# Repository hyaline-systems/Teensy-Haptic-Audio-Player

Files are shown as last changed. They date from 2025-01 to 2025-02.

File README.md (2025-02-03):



# Teensy-Haptic-Audio-Player

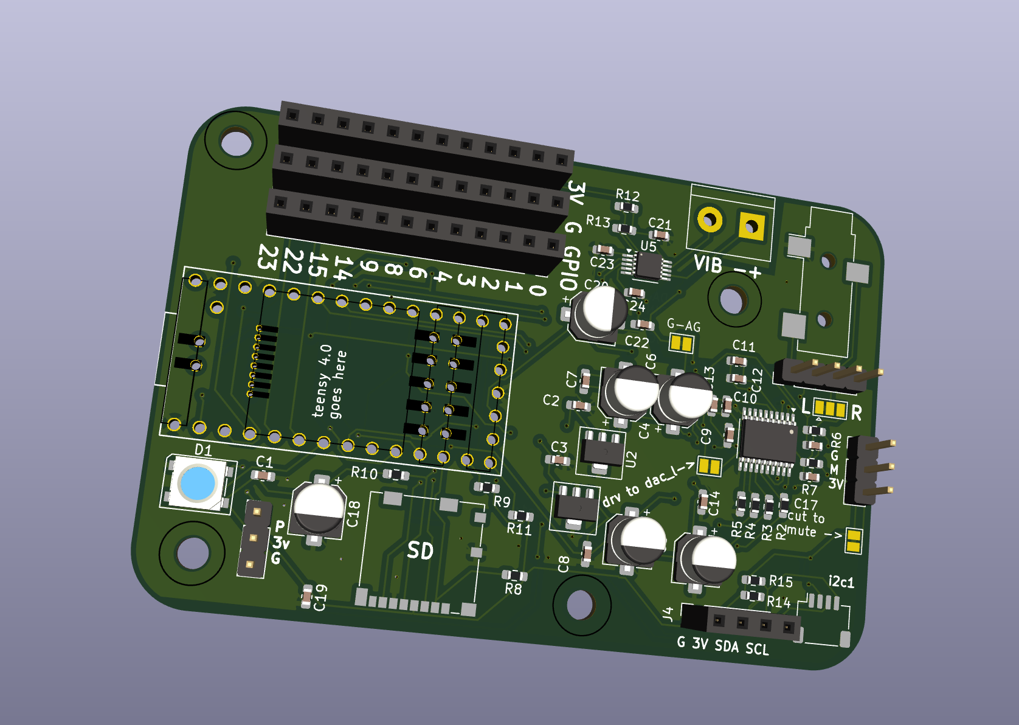
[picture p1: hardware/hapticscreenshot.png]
the PCB
 

A PCB designed for audio and haptic projects with [a Teensy 4.0](https://www.pjrc.com/store/teensy40.html). 

Among other things, it can be used to play audio from the computer as a sound card when connected via USB or from audio files via the on board SD card reader. The audio will then be output both to a 3.5mm audio jack and a haptic driver that will make a vibration motor [like this one](https://www.adafruit.com/product/1201) vibrate in sync with the audio, kinda like in a gamepad, sex toy or phone.

Another usecase is simply as a high quality audio development platform.

The whole thing is open source and hackable and is designed to be used for many different scenarios.

See [hyaline.systems](https://hyaline.systems) for more information. 

## Buying

You can buy a board, either bare (no components) or SMD-populated (no Teensy included) by sending an email to [hi@hyaline.systems](mailto:hi@hyalyne.systems).

If you just want to support the project, [consider making a donation through kofi](https://ko-fi.com/madskjeldgaard).

## Features

- Designed for the very powerful Teensy 4.0 board.
- High quality i2s stereo output DAC with 3.5mm line out jack: [PCM5102A DAC](https://www.ti.com/product/PCM5102A) – this DAC is widely compatible with all platforms and SDK's, including Arduino and C.
- SD card reader
- NeoPixel
- StemmaQT connector for easy i2c expansion.
- Optional: Hardware mute button may be connected directly to DAC.
- All unused pins broken out with lots of ground and power pins to make external connections easy
- Self-documenting board: All pins and connections are written on the board itself.

## Software

See [software/examples](software/examples) for example code using Arduino.

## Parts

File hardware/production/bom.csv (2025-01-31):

Designator | Footprint | Quantity | Value | LCSC Part #
3vpins1, GNDpins1, extra_gpio1 | PinSocket_1x12_P2.54mm_Vertical | 3 | Conn_01x12
C1, C10, C11, C12, C13, C21, C23, C24 | 0603 | 8 | 1uf
C14, C19, C2, C22, C3, C7, C8, C9 | 0603 | 8 | 0.1uf
C15, C18, C20, C4, C5, C6 | CP_Elec_5x5.7 | 6 | 10uf
C16, C17 | 0603 | 2 | 1nf
D1 | LED_SK6812_PLCC4_5.0x5.0mm_P3.2mm | 1 | SK6812
J1 | PinHeader_1x04_P2.54mm_Vertical | 1 | Conn_01x04
J2 | Jack_3.5mm_CUI_SJ-3523-SMT_Horizontal | 1 | AudioJack3
J3 | microSD_HC_Molex_104031-0811 | 1 | Micro_SD_Card
J4 | PinSocket_1x04_P2.54mm_Vertical | 1 | Conn_01x04_Pin
MUTE1, NEOPIXEL_OUT1 | PinHeader_1x03_P2.54mm_Vertical | 2 | Conn_01x03
R10, R11, R8, R9 | 0603 | 4 | 47k
R12, R13, R14, R15 | 0603 | 4 | 10k
R2, R3, R4, R5 | 0603 | 4 | 22
R6, R7 | 0603 | 2 | 470
STEMMA_QT_I2C1 | JST_SH_SM04B-SRSS-TB_1x04-1MP_P1.00mm_Horizontal | 1 | JST_SH_SM04
U1 | Teensy40_SMT | 1 | Teensy4.0
U2, U3 | SOT-89-3 | 2 | AP7365-33YG
U4 | TSSOP-20_4.4x6.5mm_P0.65mm | 1 | PCM5102A
U5 | VSSOP-10_3x3mm_P0.5mm | 1 | DRV2605LDGS
VIBMTR1 | TerminalBlock_bornier-2_P5.08mm | 1 | VIBMTR

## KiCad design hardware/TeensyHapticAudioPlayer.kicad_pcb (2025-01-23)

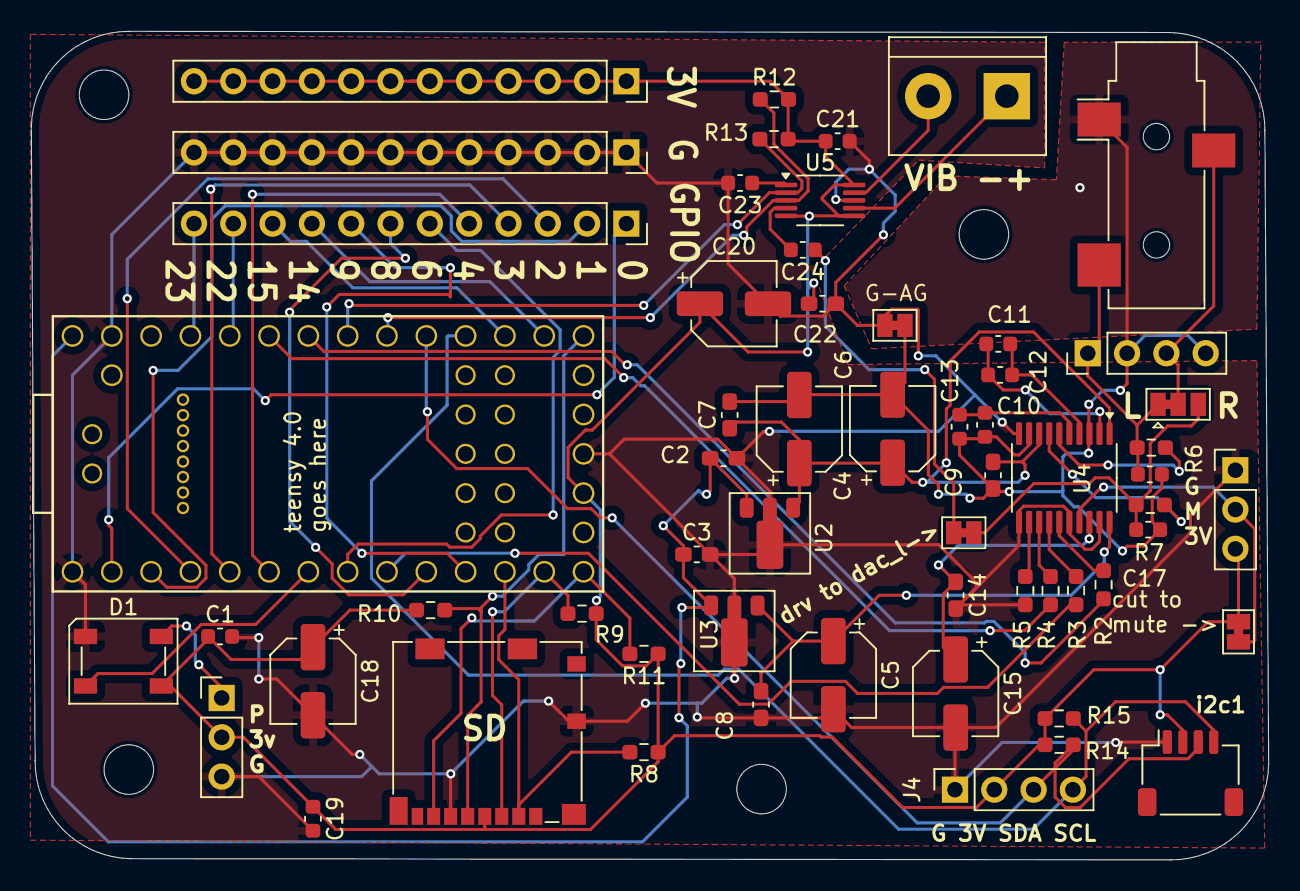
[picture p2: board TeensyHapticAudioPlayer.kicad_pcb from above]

Board: 2 copper layers, 79.9 x 53.5 mm, 63 parts (0 on the bottom side), 50 nets.

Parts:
3vpins1: Conn_01x12; PinSocket_1x12_P2.54mm_Vertical
AGND_BRIDGE1, AGND_BRIDGE2: AGND_BRIDGE; SolderJumper-2_P1.3mm_Bridged_Pad1.0x1.5mm
C1, C10, C11, C12, C13, C21, C23, C24: 1uf; C_0603_1608Metric
C2, C3, C7, C8, C9, C14, C22: 0.1uf; C_0603_1608Metric_Pad1.08x0.95mm_HandSolder
C4, C5, C6, C15, C18, C20: 10uf; CP_Elec_5x5.7
C16, C17: 1nf; C_0603_1608Metric
C19: 0.1uf; C_0603_1608Metric
D1: SK6812; LED_SK6812_PLCC4_5.0x5.0mm_P3.2mm
GNDpins1: Conn_01x12; PinSocket_1x12_P2.54mm_Vertical
H1, H2, H3, H4: MountingHole; MountingHole_3.2mm_M3
J1: Conn_01x04; PinHeader_1x04_P2.54mm_Vertical
J2: AudioJack3; Jack_3.5mm_CUI_SJ-3523-SMT_Horizontal
J3: Micro_SD_Card; microSD_HC_Molex_104031-0811
J4: Conn_01x04_Pin; PinSocket_1x04_P2.54mm_Vertical
JP1: MUTE_BRIDGE; SolderJumper-2_P1.3mm_Bridged_Pad1.0x1.5mm
JP6: SolderJumper_3_Bridged12; SolderJumper-3_P1.3mm_Bridged12_Pad1.0x1.5mm
MUTE1: Conn_01x03; PinHeader_1x03_P2.54mm_Vertical
NEOPIXEL_OUT1: Conn_01x03; PinHeader_1x03_P2.54mm_Vertical
R2, R3, R4, R5: 22; R_0603_1608Metric_Pad0.98x0.95mm_HandSolder
R6, R7: 470; R_0603_1608Metric_Pad0.98x0.95mm_HandSolder
R8, R9, R10, R11: 47k; R_0603_1608Metric_Pad0.98x0.95mm_HandSolder
R12, R13, R14, R15: 10k; R_0603_1608Metric_Pad0.98x0.95mm_HandSolder
STEMMA_QT_I2C1: JST_SH_SM04; JST_SH_SM04B-SRSS-TB_1x04-1MP_P1.00mm_Horizontal
U1: Teensy4.0; Teensy40_SMT
U2, U3: AP7365-33YG; SOT-89-3
U4: PCM5102A; TSSOP-20_4.4x6.5mm_P0.65mm
U5: DRV2605LDGS; VSSOP-10_3x3mm_P0.5mm
VIBMTR1: VIBMTR; TerminalBlock_bornier-2_P5.08mm
extra_gpio1: Conn_01x12; PinSocket_1x12_P2.54mm_Vertical

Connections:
+3.3V: 3vpins1.1, 3vpins1.2, 3vpins1.3, 3vpins1.4, 3vpins1.5, 3vpins1.6, 3vpins1.7, 3vpins1.8, 3vpins1.9, 3vpins1.10, 3vpins1.11, 3vpins1.12, C1.1, C18.1, C19.1, C20.1, C21.1, C22.1, D1.3 (VDD), J3.4 (VDD), J4.2, JP1.2 (B), MUTE1.3, NEOPIXEL_OUT1.2, R8.1, R9.1, R10.1, R11.1, R12.2, R13.2, R14.1, R15.2, STEMMA_QT_I2C1.2, U1.16 (3V3), U5.5 (EN), U5.6 (VDD/NC), U5.10 (VDD)
+5V: C2.1, C3.1, U1.33 (VIN), U2.3 (IN), U3.3 (IN)
/AGND: AGND_BRIDGE1.1 (A), C4.2, C6.2, C7.2, C9.2, C10.2, C13.2, C16.2, C17.2, J1.2, J1.4, J2.S, U4.3 (CPGND), U4.9 (AGND)
/DAC_BCK: R4.1, U1.28 (21_A7_RX5_BCLK1)
/DAC_DIN: R3.1, U1.9 (7_RX2_OUT1A)
/DAC_LRCK: R2.1, U1.27 (20_A6_TX5_LRCLK1)
/DAC_MUTE: JP1.1 (A), MUTE1.2, U4.17 (XSMT)
/DAC_OUT_L: C16.1, J1.1, J2.T, JP6.1 (A), R6.1
/DAC_OUT_R: AGND_BRIDGE2.1 (A), C17.1, JP6.3 (B), R7.1
/I2C0_SCL: R13.1, U1.26 (19_A5_SCL0), U5.2 (SCL)
/I2C0_SDA: R12.1, U1.25 (18_A4_SDA0), U5.3 (SDA)
/I2C1_SCL: J4.4, R15.1, STEMMA_QT_I2C1.4, U1.23 (16_A2_RX4_SCL1)
/I2C1_SDA: J4.3, R14.2, STEMMA_QT_I2C1.3, U1.24 (17_A3_TX4_SDA1)
/NEOPIXEL: D1.2 (DIN), U1.7 (5_IN2)
/NEOPIXEL_OUT: D1.4 (DOUT), NEOPIXEL_OUT1.1
/PCM5102A DAC/3V3A: C4.1, C6.1, C7.1, C9.1, U2.1 (OUT), U4.1 (CPVDD), U4.8 (AVDD)
/PCM5102A DAC/3V3D: C5.1, C8.1, U3.1 (OUT), U4.20 (DVDD)
/SD_CS: J3.2 (DAT3/CD), R8.2, U1.12 (10_CS_MQSR)
/SD_MISO: J3.7 (DAT0), R11.2, U1.14 (12_MISO_MQSL)
/SD_MOSI: J3.3 (CMD), R9.2, U1.13 (11_MOSI_CTX1)
/SD_SCK: J3.5 (CLK), R10.2, U1.20 (13_SCK_CRX1_LED)
/audio_out_chan2: J1.3, J2.R, JP6.2 (C)
/gp0: U1.2 (0_RX1_CRX2_CS1), extra_gpio1.1
/gp1: U1.3 (1_TX1_CTX2_MISO1), extra_gpio1.2
/gp2: U1.4 (2_OUT2), extra_gpio1.3
/gp3: U1.5 (3_LRCLK2), extra_gpio1.4
/gp4: U1.6 (4_BCLK2), extra_gpio1.5
/gp6: U1.8 (6_OUT1D), extra_gpio1.6
/gp8: U1.10 (8_TX2_IN1), extra_gpio1.7
/gp9: U1.11 (9_OUT1C), extra_gpio1.8
/gp14: U1.21 (14_A0_TX3_SPDIF_OUT), extra_gpio1.9
/gp15: U1.22 (15_A1_RX3_SPDIF_IN), extra_gpio1.10
/gp22: U1.29 (22_A8_CTX1), extra_gpio1.11
/gp23: U1.30 (23_A9_CRX1_MCLK1), extra_gpio1.12
/haptic_input: C24.2, U5.4 (IN/TRIG)
GND: AGND_BRIDGE1.2 (B), C1.2, C2.2, C3.2, C5.2, C8.2, C14.2, C15.2, C18.2, C19.2, C20.2, C21.2, C22.2, C23.2, D1.1 (VSS), GNDpins1.1, GNDpins1.2, GNDpins1.3, GNDpins1.4, GNDpins1.5, GNDpins1.6, GNDpins1.7, GNDpins1.8, GNDpins1.9, GNDpins1.10, GNDpins1.11, GNDpins1.12, J3.6 (VSS), J3.9 (SHIELD), J4.1, MUTE1.1, NEOPIXEL_OUT1.3, R5.1, STEMMA_QT_I2C1.1, U1.1 (GND), U1.17 (GND), U1.32 (GND), U2.2, U3.2, U4.10 (DEMP), U4.11 (FLT), U4.16 (FMT), U4.19 (DGND), U5.8 (GND)
unnamed: AGND_BRIDGE2.2 (B), C24.1
unnamed: R4.2, U4.13 (BCK)
unnamed: C11.2, C12.2, U4.4 (CAPM)
unnamed: C11.1, C12.1, U4.2 (CAPP)
unnamed: R3.2, U4.14 (DIN)
unnamed: C14.1, C15.1, U4.18 (LDOO)
unnamed: R2.2, U4.15 (LRCK)
unnamed: R6.2, U4.6 (OUTL)
unnamed: R7.2, U4.7 (OUTR)
unnamed: R5.2, U4.12 (SCK)
unnamed: C10.1, C13.1, U4.5 (VNEG)
unnamed: U5.7 (OUT+), VIBMTR1.1
unnamed: U5.9 (OUT-), VIBMTR1.2
unnamed: C23.1, U5.1 (REG)

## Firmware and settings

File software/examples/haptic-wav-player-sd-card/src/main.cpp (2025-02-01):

/*
This sketch reads the SD card and plays all WAV files on it.

If it's patched to the haptics driver (as it is per default), all audio should
cause the driver to activate.
*/

#include "Adafruit_DRV2605.h"
#include <Adafruit_NeoPixel.h>
#include <Audio.h>
#include <SD.h>
#include <SPI.h>
#include <SerialFlash.h>
#include <Wire.h>

constexpr auto audioDirectory = "/audiofiles";

// NeoPixel object
constexpr auto LED_PIN = 5;
constexpr auto NUM_LEDS = 1;
Adafruit_NeoPixel strip(NUM_LEDS, LED_PIN, NEO_GRB + NEO_KHZ800);

// Audio patch
AudioPlaySdWav playWav; // Add AudioPlaySdWav object
AudioOutputI2S i2s1;    // xy=365,94
AudioConnection patchCord1(playWav, 0, i2s1, 0);
AudioConnection patchCord2(playWav, 1, i2s1, 1);

constexpr auto cs = 10;
constexpr auto mosi = 11;
constexpr auto sck = 13;
constexpr auto miso = 12;

// Haptics driver
Adafruit_DRV2605 drv;

bool setupHapticDriver() {
  auto result = drv.begin();

  drv.setMode(DRV2605_MODE_AUDIOVIBE);

  // ac coupled input, puts in 0.9V bias
  drv.writeRegister8(DRV2605_REG_CONTROL1, 0x20);

  // analog input
  drv.writeRegister8(DRV2605_REG_CONTROL3, 0xA3);

  return result;
}

void setLEDGreen() {
  const auto color = strip.Color(0, 255, 0);
  strip.fill(color, 0, NUM_LEDS);
  strip.show();
}

void setLEDRed() {
  const auto color = strip.Color(255, 0, 0);
  strip.fill(color, 0, NUM_LEDS);
  strip.show();
}

void setLEDOrange() {
  const auto color = strip.Color(255, 165, 0);
  strip.fill(color, 0, NUM_LEDS);
  strip.show();
}

void setup() {
  Serial.begin(115200);
  strip.begin();
  setLEDRed();

  Serial.println("Setting up haptic driver...");
  auto hapticOK = setupHapticDriver();
  if (!hapticOK) {
    Serial.println("Haptic driver setup failed");
    while (1) {
      delay(10);
    };
  }

  Serial.println("Allocating audio memory...");
  AudioMemory(10);

  SPI.setMOSI(mosi);
  SPI.setSCK(sck);
  SPI.setMISO(miso);

  Serial.println("Initializing SD card...");
  if (!SD.begin(cs)) {
    Serial.println("SD card initialization failed!");
    while (1) {
      delay(10);
    }
  }
}

void playNextWavFile(File dir) {
  File entry = dir.openNextFile();
  if (!entry) {
    // no more files
    return;
  }
  if (!entry.isDirectory()) {
    // we only care about .WAV files
    String filename = entry.name();
    const auto weird_file =
        filename.startsWith(".") || filename.startsWith("_");
    if (filename.endsWith(".WAV") ||
        ((filename.endsWith(".wav") && !weird_file))) {
      {
        Serial.print("Playing file: ");
        Serial.println(filename);
        playWav.play(filename.c_str());
        delay(5); // wait for library to parse WAV info
        while (playWav.isPlaying()) {
          setLEDOrange();
          delay(100); // Add a small delay to avoid flooding the serial output
        }
      }
    } else {
      Serial.print("Skipping file: ");
      Serial.println(filename);
    }
    entry.close();
  }
}

void loop() {
  setLEDOrange();
  if (!playWav.isPlaying()) {
    File root = SD.open(audioDirectory);
    playNextWavFile(root);
    root.close();
  }
}

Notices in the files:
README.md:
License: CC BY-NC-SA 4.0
